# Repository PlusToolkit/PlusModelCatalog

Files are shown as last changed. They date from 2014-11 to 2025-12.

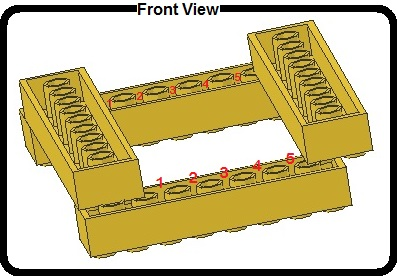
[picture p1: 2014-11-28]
fCalPhantom/fCal_L1/BuildingInstructionManual/Pictures/LegoPhantomStep2Iso.png

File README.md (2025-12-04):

# PlusModelCatalog

This repository contains 3D printable models for the Plus Toolkit

## Documentation

View the documentation at: [Read the Docs](https://plusmodelcatalog.readthedocs.io/)

## Building Documentation Locally

### Prerequisites

```bash
pip install -r docs/requirements.txt
```

This installs:
- Sphinx and extensions
- VTK for STL rendering
- Supporting packages

### Generate and Build

```bash
# Generate catalog pages from STL files
cd docs
python generate_catalog.py --repo-root .. --docs-dir .

# Build HTML documentation
sphinx-build -b html . _build/html

# View documentation
start _build/html/index.html  # Windows
# or
open _build/html/index.html   # macOS
# or
xdg-open _build/html/index.html  # Linux
```

### Quick Build Script

On Windows:
```batch
cd docs
python generate_catalog.py --repo-root .. --docs-dir .
sphinx-build -b html . _build/html
start _build\html\index.html
```

## Adding New Models

1. Add STL file to the appropriate directory (Tools, TrackingFixtures, etc.)
2. Edit the corresponding `catalog.json` file in that directory to add model metadata:
   - Add a description
   - Optionally specify explicit files if not auto-discovered
   - Optionally specify a custom preview image
3. Commit to repository
4. Documentation automatically regenerates on ReadTheDocs

### Example: Adding a New Tool

```json
// Edit Tools/catalog.json
{
  "models": {
    "MyNewTool": {
      "description": "Description of my new tool with its dimensions and purpose.",
      "files": ["MyNewTool.stl"]  // Optional if file matches model ID
    }
  }
}
```

## Contributing

Contributions of new models are welcome! Please ensure:
- STL files are clean and printable
- Include source CAD files when possible
- Add appropriate descriptions in the `catalog.json` file in the model's folder

## Support

For questions about the Plus Toolkit, visit:
- Website: https://plustoolkit.github.io/
- GitHub: https://github.com/PlusToolkit/

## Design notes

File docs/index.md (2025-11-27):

# PlusModelCatalog

Welcome to the Plus Toolkit 3D Model Catalog

```{toctree}
:maxdepth: 2
:caption: Contents:
:hidden:
catalog/tools
catalog/tracking-fixtures
catalog/fcal-phantoms
catalog/anatomy
catalog/needletutor
```

```{toctree}
:maxdepth: 1
:caption: Related Projects
:hidden:
PlusLib Documentation <https://pluslib.readthedocs.io/>
```

## About

This catalog contains freely usable, 3D-printable models of tools, tracking fixtures, calibration phantoms, and anatomical models.

## Quick Links

- [Tools](catalog/tools.md) - Tracking tools, ultrasound probes, and surgical instruments
- [Tracking Fixtures](catalog/tracking-fixtures.md) - Mounts for optical and EM trackers
- [fCal Phantoms](catalog/fcal-phantoms.md) - Calibration phantoms
- [Anatomy Models](catalog/anatomy.md) - Anatomical models for simulation
- [Needle Tutor](catalog/needletutor.md) - Components for needle insertion training

## Repository

All models are hosted on GitHub: [PlusToolkit/PlusModelCatalog](https://github.com/PlusToolkit/PlusModelCatalog)

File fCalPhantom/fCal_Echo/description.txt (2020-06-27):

fCal phantom customized for tube-shaped echo probes such as intracardiac echo (ICE) catheters and transesophageal echo (TEE) probes.
Developed by Robert Kreher (Otto-von-Guericke-University Magdeburg, Germany (https://www.ovgu.de/), Stimulate Research Campus (https://www.forschungscampus-stimulate.de/).

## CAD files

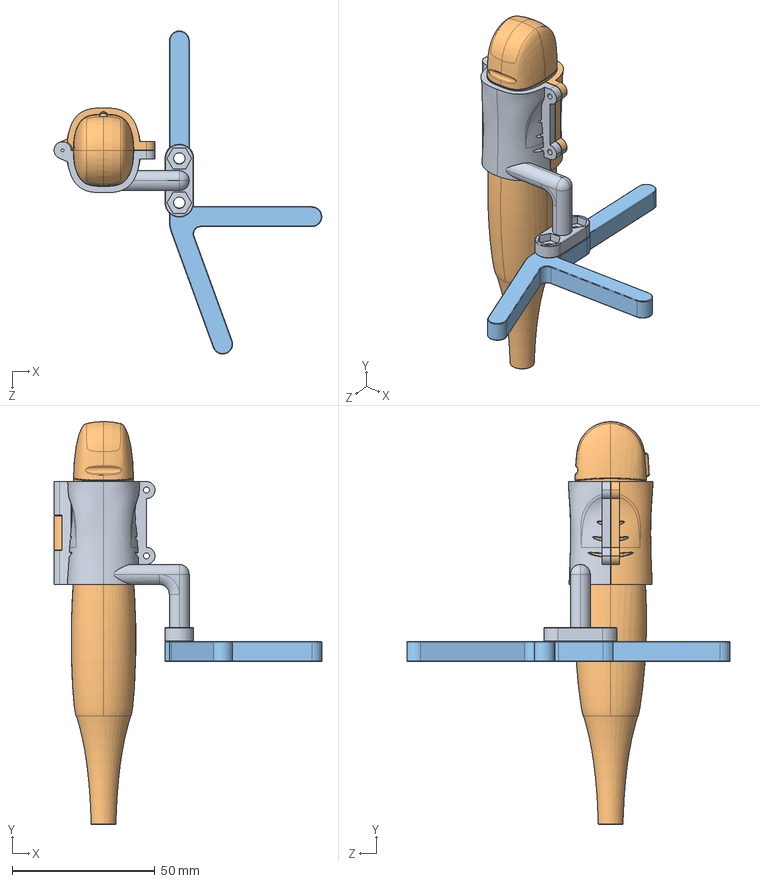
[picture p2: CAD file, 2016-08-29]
TrackingFixtures/MC10_ProbeHolder/TelemedMC10_ProbeHolder_Assembly.SLDASM
93.7 x 141.0 x 113.1 mm
TelemedMC10_ProbeHolder_MarkedSide
TelemedMC10_ProbeHolder_UnmarkedSide
TelemedMC10_ProbeHolder_OpticalTracker

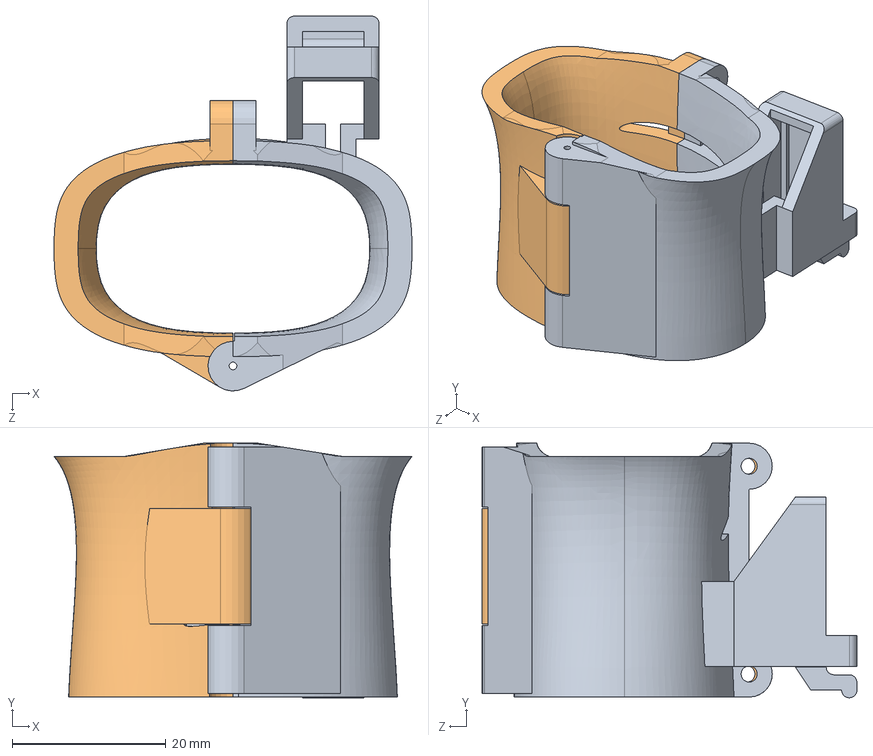
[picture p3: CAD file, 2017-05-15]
TrackingFixtures/Telemed-MicrUs-L12-SensorHolder.SLDASM
46.5 x 33.1 x 48.7 mm
TelemedHolder_L12_MarkedSide
TelemedHolder-L12_UnmarkedSide

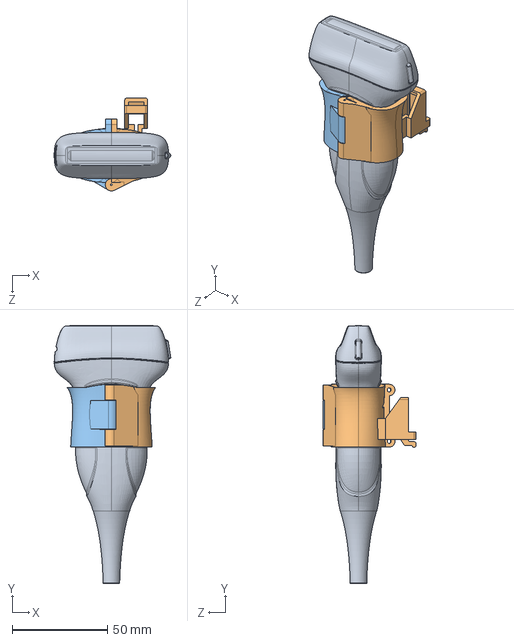
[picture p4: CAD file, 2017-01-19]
TrackingFixtures/Telemed-L12-FixtureConcept.SLDASM
61.2 x 135.3 x 48.7 mm
TelemedHolder_L12_MarkedSide
TelemedHolder-L12_UnmarkedSide

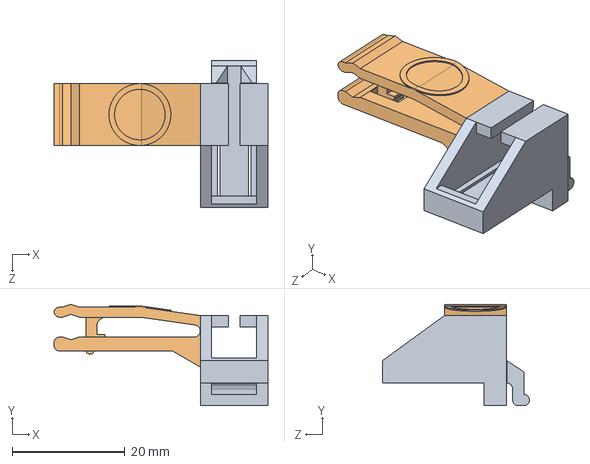
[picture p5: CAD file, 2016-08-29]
TrackingFixtures/NeedleGrabber_Parallel.SLDASM
38.0 x 18.0 x 26.1 mm
SensorHolder_2.0
NeedleGrabber_Parallel_Short

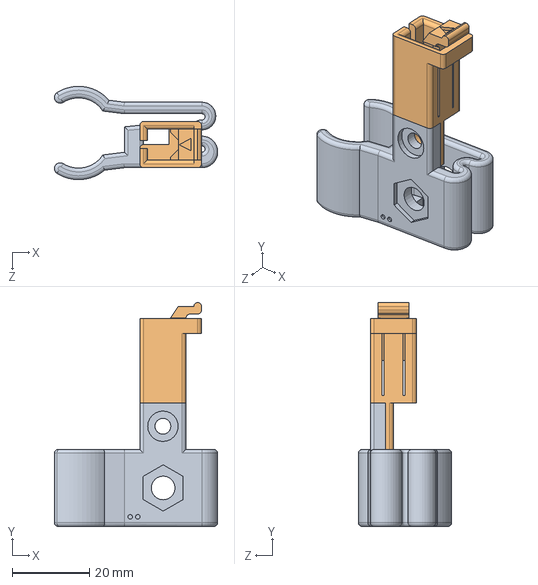
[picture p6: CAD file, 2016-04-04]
TrackingFixtures/CauteryTracking-Concept.SLDASM
42.4 x 58.1 x 24.2 mm
CauteryGrabber
SensorHolder-OneHole

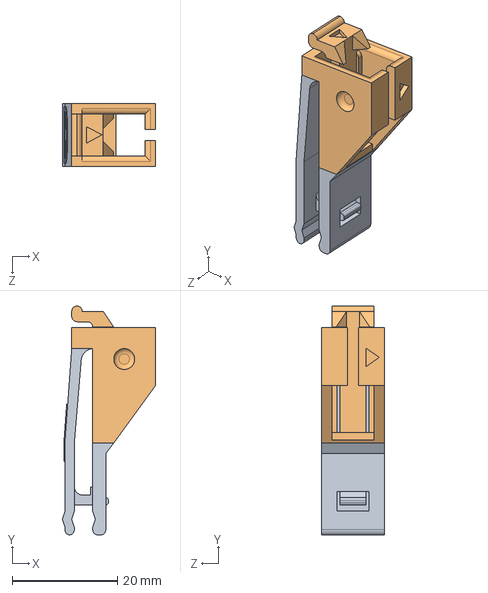
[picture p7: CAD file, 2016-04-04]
TrackingFixtures/NeedleClip-Assembly_16-20G.SLDASM
17.8 x 43.6 x 12.0 mm
NeedleGrabber_16-20G
SensorHolder_2.0

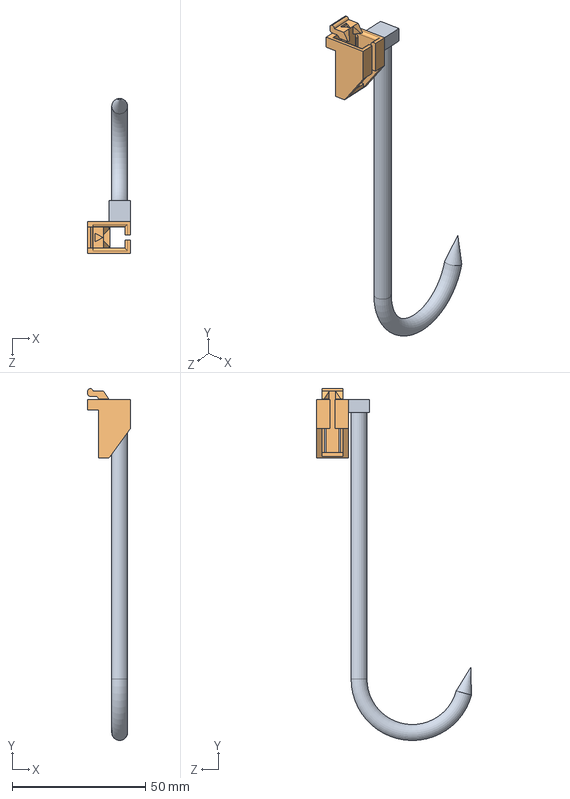
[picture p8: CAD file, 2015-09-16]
TrackingFixtures/Stylus_Candycane_100mm_WithHolder.SLDASM
16.0 x 132.1 x 58.2 mm
CandyCaneTip_100mm
SensorHolder_2.0

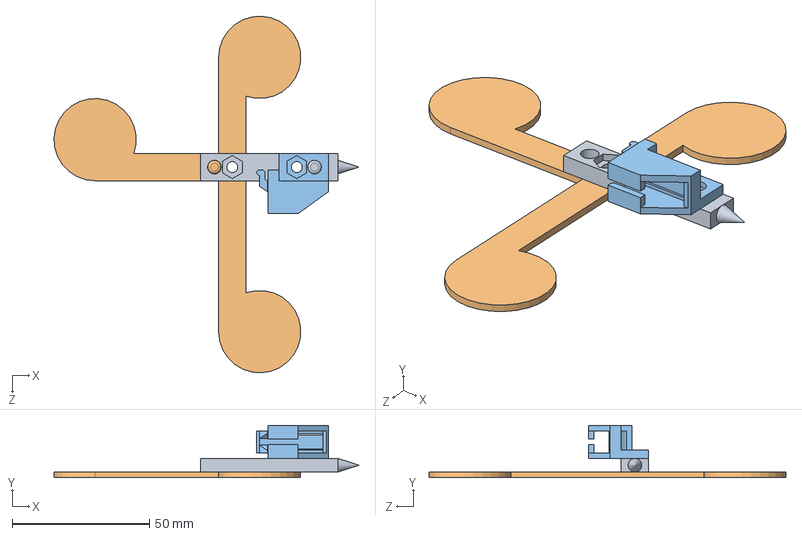
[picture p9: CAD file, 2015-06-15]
TrackingFixtures/MicronAscensionTracking-Concept.SLDASM
111.2 x 19.0 x 130.0 mm
Pointer-TwoConnectors
MicronPlate01
SensorHolderConnector_1.0

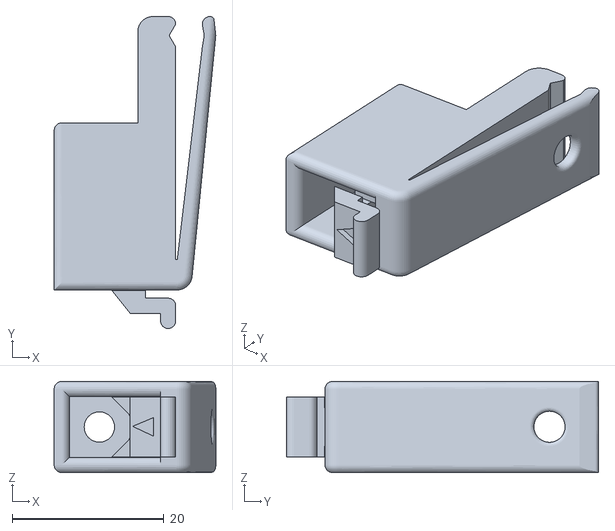
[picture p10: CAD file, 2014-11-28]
TrackingFixtures/NeedleGrabberFlappy-Assembly_1.0.stl
21.3 x 41.1 x 12.0

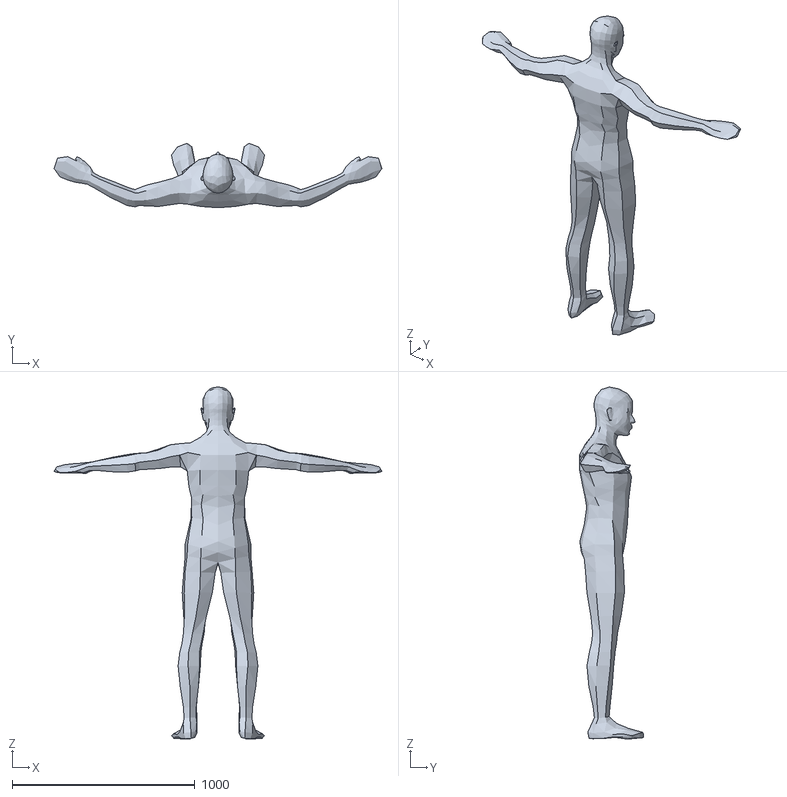
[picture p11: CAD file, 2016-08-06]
Anatomy/HumanSimple.stl
1795.8 x 352.8 x 1927.8

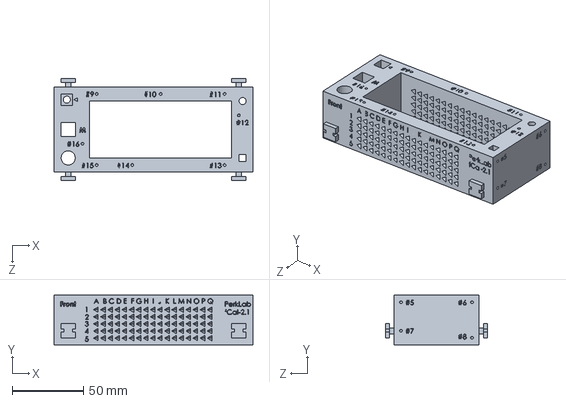
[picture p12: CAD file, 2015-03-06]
fCalPhantom/fCal_2/fCal_2.1.SLDPRT
140.0 x 35.0 x 72.0 mm

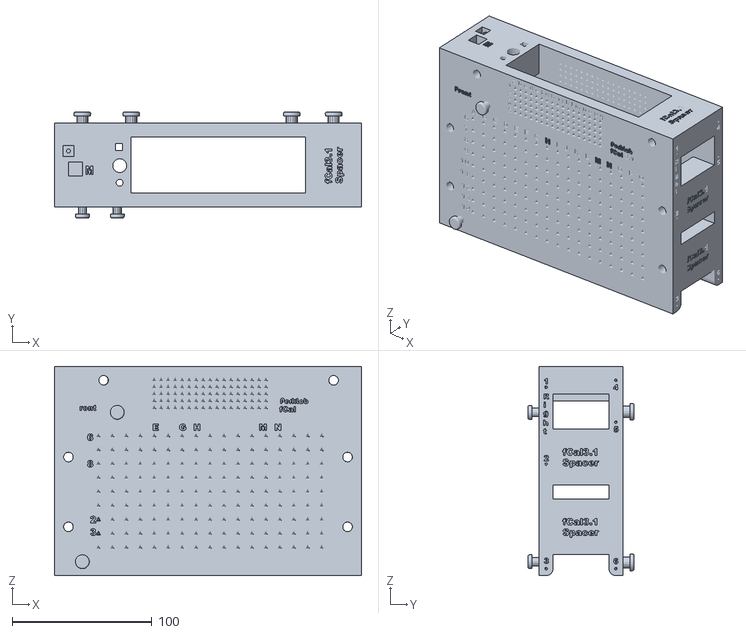
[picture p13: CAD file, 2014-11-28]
fCalPhantom/fCal_3/fCal_3.1.stl
220.0 x 76.0 x 150.0

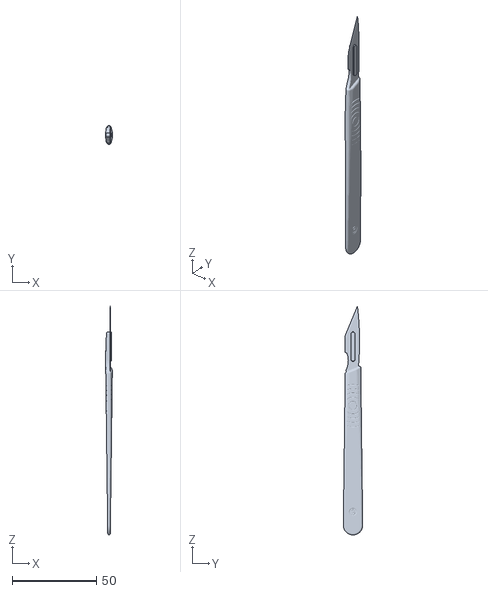
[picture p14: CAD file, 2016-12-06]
Tools/Scalpel.stl
3.97 x 11.4 x 135.7

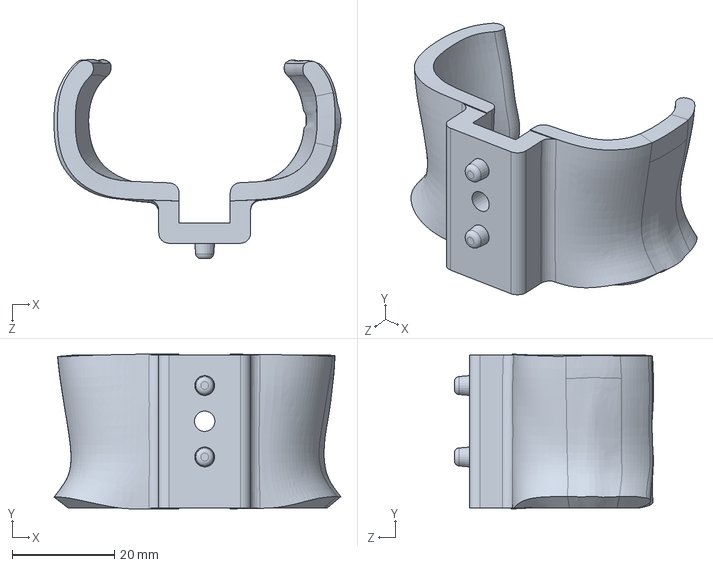
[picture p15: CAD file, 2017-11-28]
TrackingFixtures/GE_ML6-15-D/GeMl615D_Clip_v01.SLDPRT
56.2 x 30.3 x 39.0 mm

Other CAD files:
TrackingFixtures/MC10_ProbeHolder/TelemedMC10_ProbeHolder_MarkedSide.SLDPRT
TrackingFixtures/MicronTracker/MarkerHolder_120mm_Winged_1.0.stl
TrackingFixtures/MultiModalityTracking/SolidWorks/peg1.SLDPRT
TrackingFixtures/OpticalMarkerTracker/Marker-80.SLDPRT
Tools/Cautery.SLDPRT
Tools/Cautery.stl
Tools/Needle_BardDuaLok57.stl
Tools/UsProbe_SPL40.stl
Tools/UsProbe_Telemed_L12.stl
Tools/UsProbe_Ultrasonix_C5-2_60.stl
Tools/UsProbe_Ultrasonix_EC9-5_10.stl
Tools/UsProbe_Ultrasonix_L14-5_38.stl
TrackingFixtures/ArmL-30.STL
TrackingFixtures/Ascension800Holder_ThreeHolesSide.SLDPRT
TrackingFixtures/Ascension800Holder_ThreeHolesSide.STL
TrackingFixtures/Ascension800Holder_ThreeHolesUp.SLDPRT
TrackingFixtures/Ascension800Holder_ThreeHolesUp.STL
TrackingFixtures/AscensionStyleAuroraHolder_1.0.SLDPRT
TrackingFixtures/AscensionStyleAuroraHolder_1.0.STL
TrackingFixtures/Block4x4-ThreeHoles.SLDPRT
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

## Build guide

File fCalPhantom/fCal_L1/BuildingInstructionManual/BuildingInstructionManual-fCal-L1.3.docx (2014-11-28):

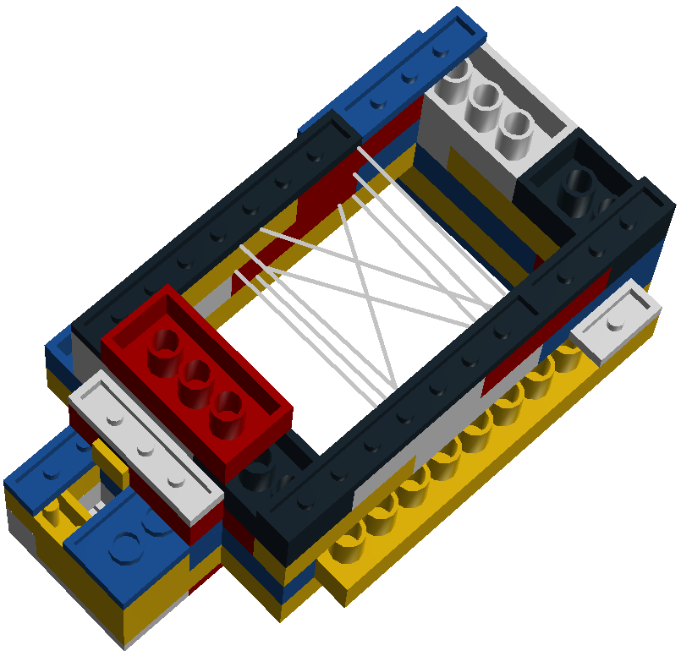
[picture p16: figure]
LegoPhantom1
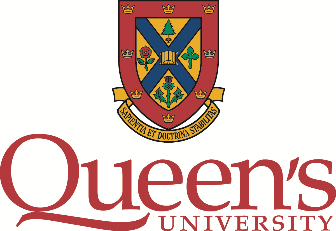
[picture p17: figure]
QueensLogo_Full_4C
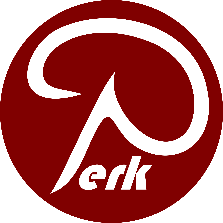
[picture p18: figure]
PerkLogo2010-round-1200dpi

Queen’s University Laboratory for Percutaneous Surgery

## Introduction

This instructional booklet is a detailed explanation of how to build the Lego Phantom. The approximate building time is 30 minutes.

## Developer

This Lego Phantom design and instructional booklet were developed in the Queen's University Laboratory for Percutaneous Surgery (http://perk.cs.queensu.ca/) (Perk Lab) in Kingston, Ontario by Ryan Walsh in June 2013.

## Purpose

The purpose of this instruction booklet is to clearly describe the process of building an identical phantom from a cheap and accessible material (ie. Lego). The Lego Phantom is to be used during the calibration of an ultrasound imager using fCal from the Plus Library (https://www.assembla.com/spaces/plus/wiki). The goal of this project was to create the phantom from a material that is readily available to any person and relatively cheap (less than $20 CAD). The Lego Phantom was also required to maintain the precision and accuracy of other phantom models (less than 1 millimetre of error). This will allow any experiments performed in the Perk Lab (http://perk.cs.queensu.ca/) be easily recreated in any other lab.

## Provided Components

1. This instructional booklet (InstructionManual.pdf)
2. A 3D CAD file of the Lego Phantom to be used in fCal (LegoPhantom.stl)
3. A configuration file of the Lego Phantom to be used in fCal (PlusConfiguration_Sonix_Ascension_LegoPhantom.xml)

## Excluded Components

1. Lego blocks (Lego blocks can be purchased in 24 different countries here (http://shop.lego.com/en-CA/Pick-A-Brick-ByTheme))
2. Wire
3. fCal, the Plus Library and other software (fCal and the Plus Library can be found here (https://www.assembla.com/spaces/plus/wiki))
4. Ultrasound Imager and other related hardware
5. Sonix GPS and Ascension Technology Corporation 3D tracking related hardware

## Preparation

It is recommended that all Lego blocks be washed before they are used in the Lego Phantom to remove any large particles that could create noise during Spatial Calibration in fCal. Washing instructions can be found here (http://service.lego.com/en-us/helptopics/) under Products->General Product Queries->How do I sanitize or wash my LEGO Elements.

## Proper Lego Phantom Orientation

To understand the proper orientation of the Lego Phantom, refer to Figure 1.

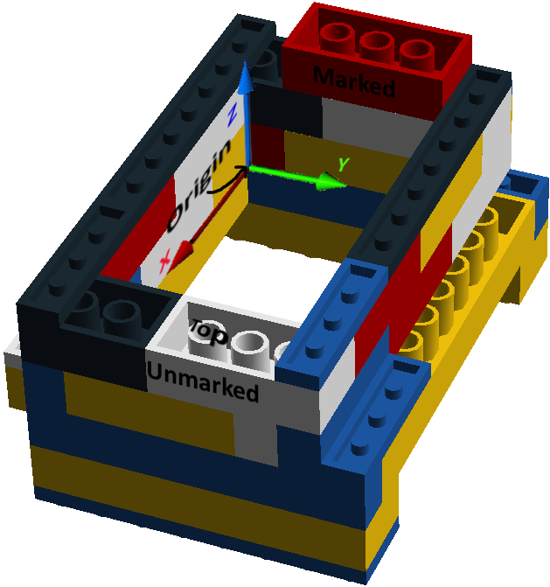
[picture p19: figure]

Figure 1: Lego Phantom Orientation and Coordinate System

Note that the phantom is designed to be used in a way that may seem “upside down” to other Lego users. Additionally, while the colour of the blocks is arbitrary and can be completely ignored, it is strongly recommended that a bright red 2x4 brick be placed on the marked side of the phantom as shown in Figure 1. This block is used to make Spatial Calibration in fCal easier for the user since an ultrasound probe has a marked and unmarked side. The marked side of the ultrasound probe should be held closest to the marked side of the Lego Phantom during Spatial Calibration. The ultrasound probe should be held above the top of the Lego Phantom while imaging the wire pattern during Spatial Calibration.

## Wire Used in the Perk Lab (http://perk.cs.queensu.ca/)

A total of 3 25 centimetre lengths of cotton yarn string were used in the Lego Phantom. Each string was used as one layer of N-Wire. The strings had a diameter of 0.3 millimetres or 0.16 millimetres when compressed. It is important that a wire has the same compressed diameter as those used in the Perk Lab (http://perk.cs.queensu.ca/) because the diameter of each wire affects their description in the Plus configuration file (PlusConfiguration_Sonix_Ascension_LegoPhantom.xml).

## N-Wire Threading

Threading instructions can be found on pages 30, 31 and 33 of this booklet. Each step corresponds to one layer of wire in an ‘N’ shaped pattern.

It is very important that the location of the wires is exactly identical on all phantoms. As a result, each wire should be pulled taught and tightly against the inside of the “nub” (the circular extrusion of the piece that will be placed above it) as shown in the diagrams. To do this, only loosely attach the Lego brick above each layer of wire. Then, when the wire is completely taught in the correct position, tightly secure the brick above the layer of wire.

## Inserting the Electromagnetic Tracker Reference

It is very important that the electromagnetic tracker reference does not move relative to the Lego Phantom during the ultrasound calibration. See Figure 2 for instructions on how to properly insert and secure the probe.

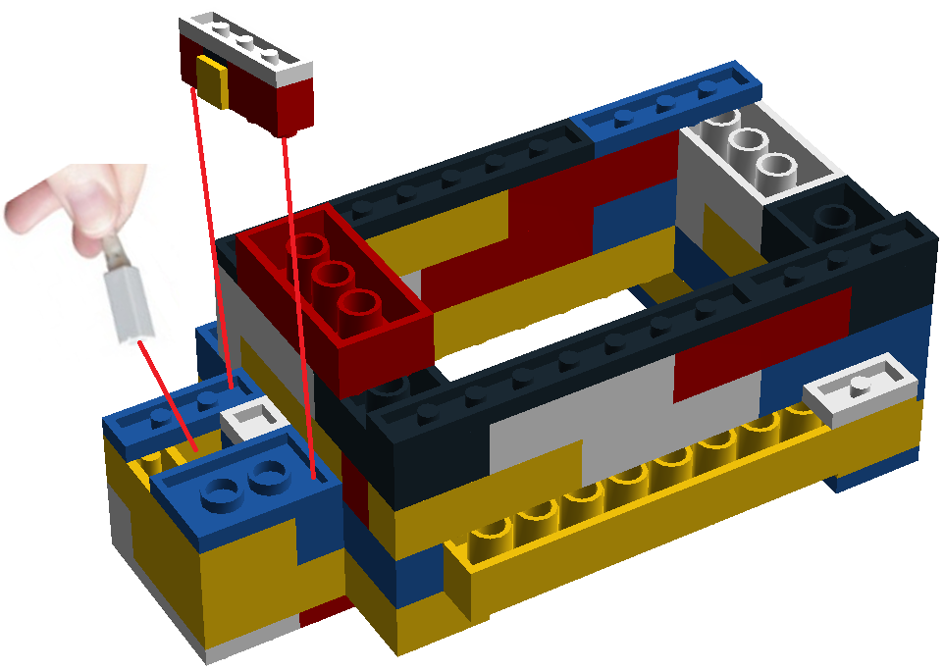
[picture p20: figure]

Figure 2: Inserting and Securing the Electromagnetic Tracker Probe

The orientation of the electromagnetic tracker reference does not matter, but it is important that it is inserted all the way into its slot and tightly secured by the clamp piece.

## Registration Landmarks

Registration landmarks are used during the Phantom Registration in fCal. There are 8 unique registration landmarks on the Lego Phantom that must be identified in order. Refer to Figure 3 for the location of each registration landmark.

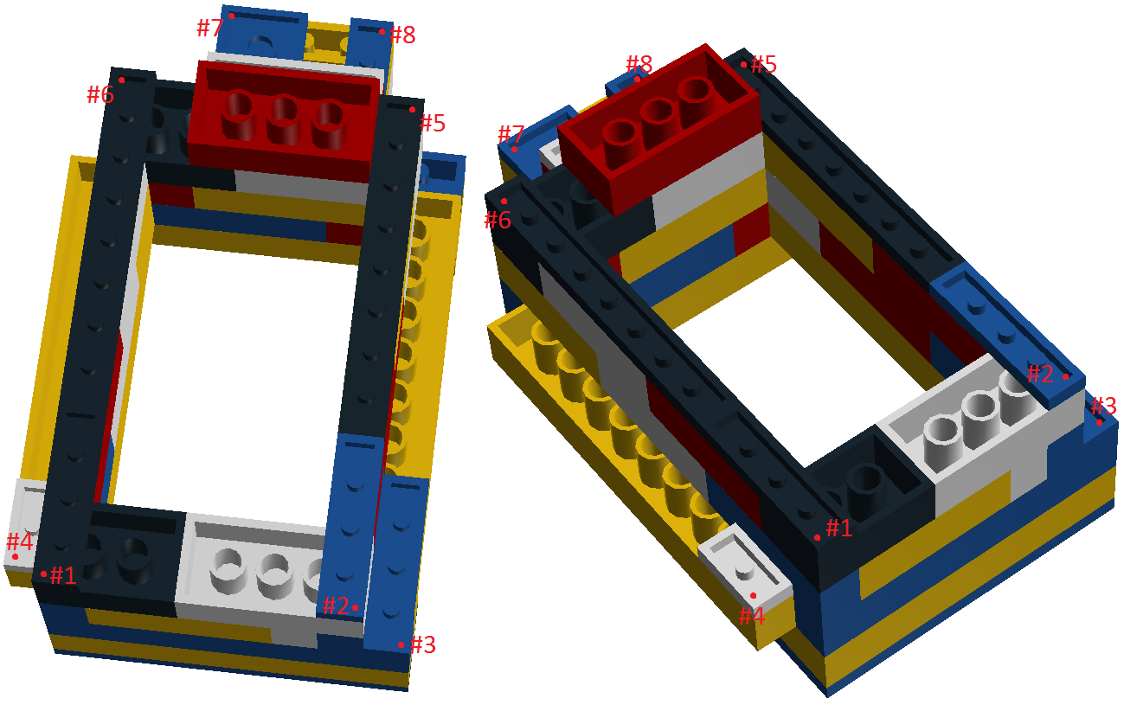
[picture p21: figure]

Figure 3: Location of the Lego Phantom registration landmarks

Note that – in order to define a unique point – when identifying these reference points, the stylus tip should be inserted into the tile piece and pressed against the bottom corner where the two edges meet.

## Important Information

The purpose of this instructional booklet is not to teach a user how to use fCal and the Plus Library (https://www.assembla.com/spaces/plus/wiki). Therefore, it is assumed that the user has a working knowledge of ultrasound calibration using fCal in the Plus Library (https://www.assembla.com/spaces/plus/wiki).

In order to be able to visualize the Lego Phantom during Phantom Registration in fCal, the Plus configuration file (PlusConfiguration_Sonix_Ascension_LegoPhantom.xml) must contain the path of the 3D CAD file (LegoPhantom.stl). Since each user may have a different path, none has been included in the provided Plus configuration file (PlusConfiguration_Sonix_Ascension_LegoPhantom.xml). Therefore, if a user wishes to change the directory of either the Plus configuration file or the 3D CAD file, they must add the absolute path (from the root directory) of the 3D CAD file to line 105 of the Plus configuration file.

Not all Lego blocks need to be identical to those used in this instruction set. The purpose of the Lego Phantom is to be accessible to anyone anywhere in the world. Therefore, things like colours of the blocks (it is strongly recommended that the bright red 2x4 brick on the marked side of the Lego Phantom be included for orientation purposes), symbols on them and even the number of blocks used (eg. a 2x4 brick can be replaced with 2 2x2 bricks as long as the dimensions of the Lego Phantom as a whole do not change) are unimportant. However, it is crucial that the location of each NWire’s start and end point and each reference point be exactly where they are shown in this instructional booklet for a proper ultrasound calibration.

The Lego Phantom model described in this instructional booklet is 1.3.

## Frequently Asked Questions

Question: I am getting a large error (greater than 1 millimetre) after I perform a Spatial Calibration in fCal. What is wrong?

Answer: There must be an inconsistency between your Lego Phantom N-Wire pattern and the one described in the provided Plus configuration file (PlusConfiguration_Sonix_Ascension_LegoPhantom.xml). You should try carefully threading your Lego Phantom another time. If you wish to view the Plus configuration file to find any discrepancies and fix them (either in the configuration file or on your Lego Phantom), open the plus configuration file with a text editor. On lines 146 through 158, you will find the ordered threetuples describing the x, y, and z coordinate of the start point and end point of each wire spanning the Lego Phantom (the x, y and z values are in millimetres from the origin). Refer to Figure 1 in the Proper Lego Phantom Orientation section to understand the phantom coordinate system.

## Parts List

## Building Instructions

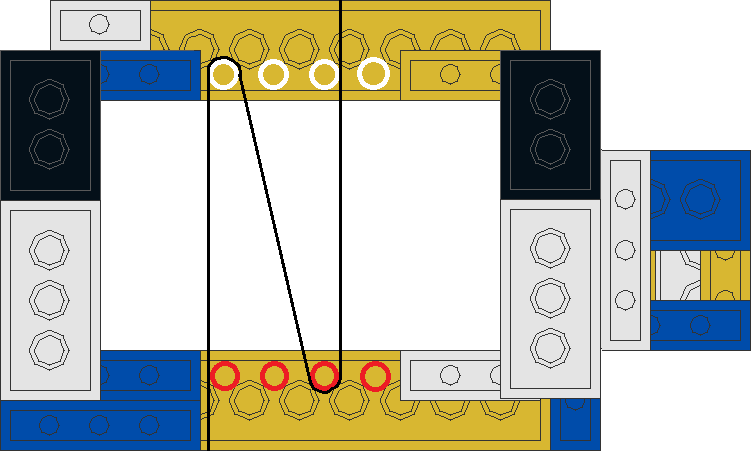
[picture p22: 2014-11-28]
fCalPhantom/fCal_L1/BuildingInstructionManual/Pictures/bottomNWire_above.png

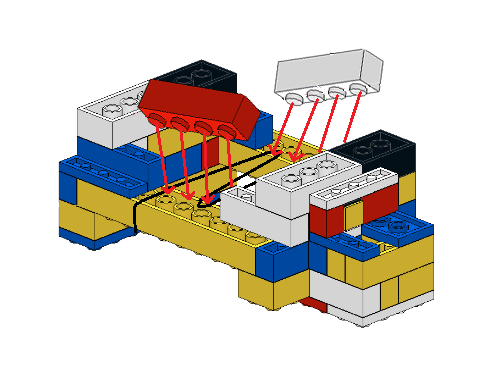
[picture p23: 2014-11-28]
fCalPhantom/fCal_L1/BuildingInstructionManual/Pictures/bottomNWire_iso.png

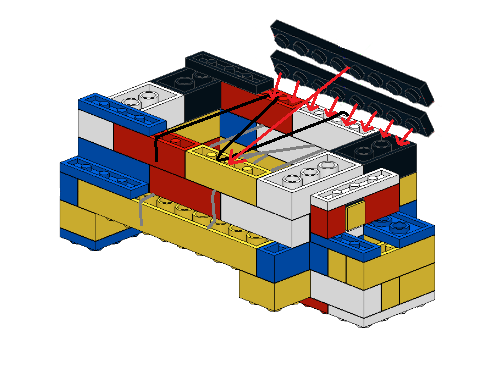
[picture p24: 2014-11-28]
fCalPhantom/fCal_L1/BuildingInstructionManual/Pictures/topNWire_iso.png

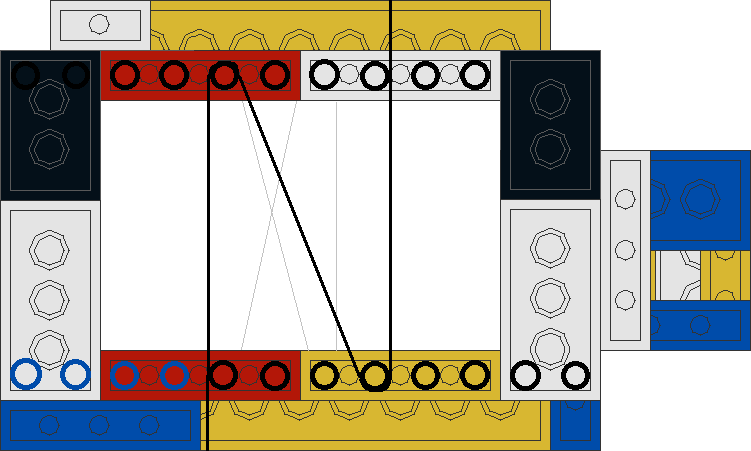
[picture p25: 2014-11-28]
fCalPhantom/fCal_L1/BuildingInstructionManual/Pictures/topNWire_above.png

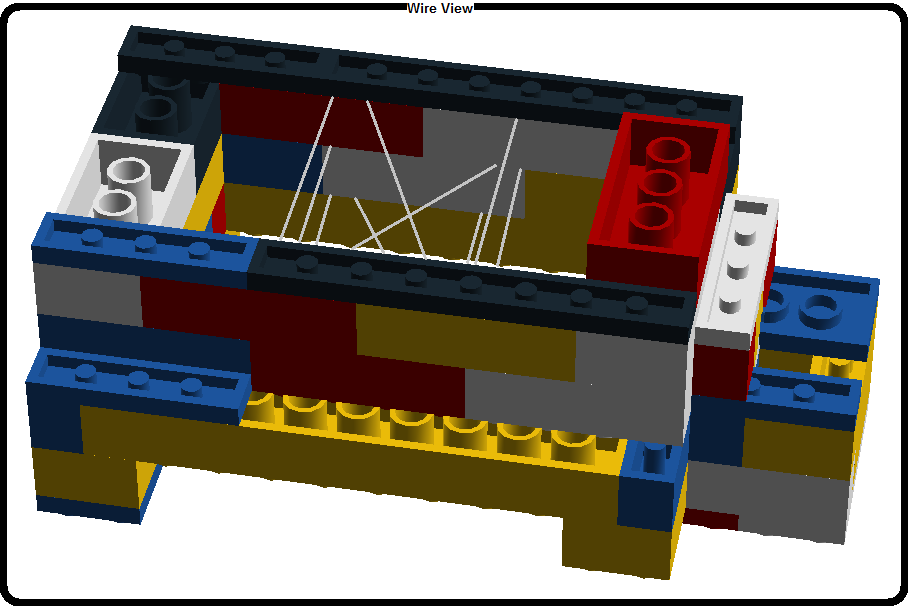
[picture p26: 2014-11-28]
fCalPhantom/fCal_L1/BuildingInstructionManual/Pictures/LegoPhantom1.3_wireView.png

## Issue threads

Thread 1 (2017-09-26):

Create clip-on fixture for Telemed ultrasound probes

Sunderlandkyl, 2017-09-26:
(No description)

Migrated from https://app.assembla.com/spaces/plus/tickets/1183/details

Sunderlandkyl, 2017-10-19:
This issue was moved to PlusToolkit/PlusLib#236

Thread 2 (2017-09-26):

Create printable markers compatible with Medronic Stealth Station

Sunderlandkyl, 2017-09-26:
(No description)

Migrated from https://app.assembla.com/spaces/plus/tickets/1189/details

Sunderlandkyl, 2017-09-26:
2017-05-09 11:01
Tamas Ungi
Re #1189: One tool added.
Committed to: plus
In plus:5073

Sunderlandkyl, 2017-10-19:
This issue was moved to PlusToolkit/PlusLib#237

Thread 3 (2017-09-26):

Move all EM field distortion mapping tool models to model catalog

Sunderlandkyl, 2017-09-26:
SlicerIgtAssembla\EmFieldDist\models

Migrated from https://app.assembla.com/spaces/plus/tickets/1023/details

Sunderlandkyl, 2017-10-19:
This issue was moved to PlusToolkit/PlusLib#238

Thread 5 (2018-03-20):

STL model of Ultrasonix BPC8-4/10 & BPL9-5/55 Transrectal probe

ai-ray, 2018-03-20:
Dear All,
for a starting project, I need the 3D model of the BPC8-4/10 & BPL9-5/55 Transrectal probe.

Since I think there are other groups using the same probe, is it possible to add this model to the repository?

Thanks in advance for your support

ungi, 2018-03-20:
Hi. I haven't used those models in the past, and none of my past Ultrasonix contacts work there anymore. If you can get a copy of those models, I would be happy to add them to the repository.

lassoan, 2018-03-20:
@ungi That's the biplane transrectal Ultrasonix probe. It has a very simple geometry, so it could be probably measured and modeled relatively easily, but it would probably still take a couple of hours.

@ai-ray Would you like to try to model it using AutoCAD Fusion 360 software? (it is free)
If it helps, we may acquire a 3D scan of it that may help in the modeling.

ungi, 2018-03-20:
True. It wouldn't take much time to make a model in Fusion 360 after surface scanning. I am working on a tutorial that is very similar to this task. In this video I'm designing a clip that matches the probe surface, but the probe itself could be modeled similarly. The video is unfinished and there is no narration yet, but here is a preview: https://1drv.ms/v/s!AhiABcbe1DBygotebJEY-OcNV2cXPg

mxochicale, 2019-11-14:
Hi @ungi , thanks for sharing the nice video. I wondering if that is a CT scan of the probe and what where the parameters you used to perform the scanning. Also, it would be nice to know if there are any precautions if one decides to scan a ultrasound probe with a CT scanner.

ungi, 2019-11-14:
Yes, CT scan. I wasn't there when they scanned it, but I don't think there are any precautions. X-ray is harmless to the ultrasound transducer. The CT technician will probably have a good guess what parameters to use.

Closed 2021-08-17.

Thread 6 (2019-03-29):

suggestions for probe holder

fcenni, 2019-03-29:
Hi,
I am working on a project for making a probe holder for this probe (from Telemed company): HL9.0/60/128Z-2 transducer. I got some ideas from your previous work here http://perk-software.cs.queensu.ca/plus/doc/nightly/modelcatalog/
I have some questions: do you recommend a single part (so a bit flexible), or 2 parts with an hinge? Which material to use for printing and for the type of hinge/s? Any suggestions/feedback is welcome!
Thanks for your help,
Francesco

ungi, 2019-03-29:
Hi, ask for the CAD model of the transducer from Telemed. I have asked twice for different transducers and they have sent me the outer shell models for free. Once you have the model, you may send it to me so I can show how I would design the clip. Or you can try yourself. The best designs for me are the ones designed as one piece that elastically snaps to the probe. We don't have the latest designs on the model catalog.

u0078867, 2019-03-29:
Hi, I am Francesco's colleague who will design the probe holder (for the snap-fit markers-holder shaft we already have an idea using a cantilever). I had the feeling the single-piece solution is better. We have a couple of 3D FDM printers here available. What material would you suggest? Nylon fibers? How thick would you recommend the elastic probe "jacket"? The thinner the more flexible, but also the more fragile ...

Thanks and regards!

ungi, 2019-03-31:
Hi, I have not experimented with different materials or settings. Some of our printers have PLA, and other ABS, both work. I use 0.8 mm shell thickness (2x nozzle diameter). And 15-20% infill. The clip itself is 3-4 mm thick, depending on how tight we want it. I usually just experiment with 0.1-0.2 mm offsets inside to make it more stable. I'm sharing this information as a reference point for you, but I'm sure these are not the optimal settings. But when a clip just works for me, I stop improving it for lack of time.

u0078867, 2019-11-14:
Forgot to closer this, but we came up with a our own design, we can share it if useful to the community.

Closed 2021-08-17.

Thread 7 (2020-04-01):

How to assemble fCal3 phantom

timirbarua, 2020-04-01:
I am building a phantom for ultrasound calibration. But confuse about which one is better between glue and screw-nuts for joining the phantom pieces. Although I prefer screw nuts but have no idea about configuration of screw-nuts for perklab fcal3.1 phantom. If anybody has any idea which one is convenient and if screw-nuts please put a link for detail information. Thanks in advance.

ungi, 2020-04-01:
For calibration, your primary goal is to collect calibration points as close to the corners of the image as possible. So, your tracked calibration phantom (either N-wires or stylus tip) needs to be as close to the corners of the image as possible. I would only use fCal phantom if you have no way to use a tracked stylus to collect calibration points. E.g. you need to clip on your tracker for every procedure, you cannot clip in the same position, and you need to maintain the tracked probe sterile. Otherwise, I would just use a tracked stylus and point at the image corners with it.

timirbarua, 2020-04-02:
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
I provided the picture of phantom pieces. Could you tell me how can I attach those pieces?

lassoan, 2021-08-17:
The phantom was designed to be assembled with screw-nuts. This model shows how to put the pieces together: https://github.com/PlusToolkit/PlusModelCatalog/blob/master/fCalPhantom/fCal_3/fCal_3.1.stl

Closed 2021-08-17.

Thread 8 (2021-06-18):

stl model of GE GE C1-6-D probe

aubest, 2021-06-18:
Hi, ，is it possible to add this model to the repository? Or where can I download the GE probe 3D model?
Thank You.

lassoan, 2021-06-18:
Unfortunately, we don't have the model of this probe.

Closed 2021-06-18.

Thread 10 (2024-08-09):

Request for Assistance with 3D Printing Issues: Telemed L12 and Ultrasonics L14-5_38 STL Files

NiltonANeto, 2024-08-09:
Dear Queen's University Members,

I hope this message finds you well.

My name is Nilton, and I am part of the University of São Paulo (USP) in Brazil. I am reaching out to request your assistance with the use of STL files for 3D printing, specifically the Telemed L12 and Ultrasonics L14-5_38 models. My goal is to conduct experiments with these transducers in water, and I would like to print them to verify the sealing before using the actual transducers.

However, I am encountering an issue during the printing process. The software indicates that the solid is "non-manifold," which prevents proper printing—only the supports are printed, while the shell does not appear. I was able to correct the mesh issues with the Telemed model using Fusion 360 (I am attaching the corrected file for your reference). Unfortunately, I have not been successful in resolving the issues with the L14-5_38 model (as shown in the attached image).

If possible, I would greatly appreciate it if you could provide the .obj file or the original model in a format other than STL so that I can attempt to fix the problem on my end. Alternatively, if it would be easier for you, I kindly request your assistance in correcting the issues with the L14-5_38 model.

Thank you very much for your attention and support.

Sincerely,
Nilton Assugeni Neto
Electrical Engineer, Federal University of Triângulo Mineiro (UFTM)
Master’s Student in Applied Physics to Medicine and Biology, University of São Paulo (USP)

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

[Telemed_L12.zip](https://github.com/user-attachments/files/16564094/Telemed_L12.zip)

ungi, 2024-08-09:
Hi Nilton, I got the L14-5 model from Telemed in SLDASM format. I could import it to Fusion 360. I didn't get permission to share the model on a public website like this so please contact me or Telemed directly for the model files. Thanks.

NiltonANeto, 2024-08-14:
Hi Ungi, thank you for your response. I sent you an email yesterday with my contact information, requesting details about the model.

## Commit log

2014-11-28 re #929: Moved all 3D models to a new subproject for automatic catalog generation
    [CauteryAssembly-Concept.cfg, CauteryHolder_1.0.stl, Concept_ScoliosisMicronTracker_2.0.cfg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]
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2014-12-01 Re #929: Removing old, unstable needle clip.
    [NeedleClip-Assembly_1.0.cfg, NeedleClip-Assembly_1.0.stl, NeedleClip-Assembly_1.1.cfg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]
2014-12-01 re #929: Removed obsolete MicronTracker tracking fixtures
    [MicronHolder1_v01.stl, MicronStylus-1.0.stl]
2015-01-06 Re #957: Leave a bit more room for the needle in bag.
    [NeedleGrabber-SensorBagHolder_1.0.cfg, NeedleGrabber-SensorBagHolder_1.0.stl, NeedleGrabber-SensorHolder_1.0.cfg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]
2015-01-06 Re #957: Added holes to make printer support material wash out faster.
    [NeedleHubClip-Assembly_1.5mm_1.0.cfg, NeedleHubClip-Assembly_1.5mm_1.0.stl, SensorHolder-Ordered-HolesInterface_2mm_1.0.stl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]
2015-01-06 re #957: Fixed model catalog build error (NeedleGrabber-SensorBagHolder_1.0.stl file was deleted but still kept in the catalog contents file). Also added dashboard submission scripts to get notificat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
2015-01-07 Re #957: Started working on needle hub grabber.
    [LocNeedle_1.0.stl]
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2015-01-14 Re #957: Deleting model that failed in practice.
    [NeedleHubClip-Assembly_1.5mm_1.0.cfg, NeedleHubClip-Assembly_1.5mm_1.0.stl]
2015-01-22 Re #957: Adding new SensorHolder designed in SolidWorks.
    [SensorHolder_1.0.SLDPRT, SensorHolder_1.0.STL]
2015-01-29 Re #957: Started working on needle hub grabber in SW.
    [NeedleHubGrabber_1.0.SLDPRT, locneedle_1.0.SLDPRT]
2015-02-02 Re #957: Removing old sensor holder that we don't use anymore.
    [SensorHolder.stl]
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2015-02-25 re #801: First version of the new fCal-2 phantom with triangle holes
    The landmark positions (and sensor holder positions) are different, so new config files are needed.
    [fCal-2.1.SLDPRT, fCal-2.1.stl]
2015-02-25 re #801: Renamed fCal_2.1 phantom files for consistency
    [fCal_2.1.SLDPRT, fCal_2.1.stl]
2015-03-06 re #801: Added second sensor fix hole and some additional labels to fCal_2.1 phantom. Added geometry description file.
    [fCal_2.1.SLDPRT, fCal_2.1.stl]
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2015-05-06 Re #990: Adding peg for Polaris reflective balls.
    [PolarisPeg.SLDPRT]
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2015-06-09 Re #990: Needle clip in SW 2015 format. Image added for printer orientation.
    [NeedleClip-Assembly_16-20G.SLDASM, NeedleClip-Assembly_16-20G.STL, NeedleGrabber_16-20G.SLDPRT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]
2015-06-12 Re #990: Clipping part was too weak. Also made the sensor bracket flexible.
    [NeedleClip-Assembly_16-20G.SLDASM, NeedleClip-Assembly_16-20G.STL, NeedleGrabber_16-20G.SLDPRT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]
2015-06-15 Re #990: Micron-Ascension dual tracker fixture.
    [MicronAscensionTracking-Concept.SLDASM, MicronPlate01.SLDPRT, NeedleClip-Assembly_16-20G.SLDASM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]
2015-06-15 Re #990: Working on Micron-Ascension dual tracking parts.
    [MicronAscensionTracking-Concept.SLDASM, MicronPlate01.STL, NeedleClip-Assembly_16-20G.STL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]
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2015-12-02 Re #990: Updated NeedleClip, and started orientation marker in SW.
    [NeedleClip-Assembly_16-20G.SLDASM, NeedleClip-Assembly_16-20G.STL, OrientationLR-Plane.SLDPRT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]
2015-12-03 Re #990: Making sensor holder more general. New OrientationLR tool for more tape space and SW format.
    [NeedleClip-Assembly_16-20G.SLDASM, OrientationLR-Plane.SLDPRT, OrientationLR-Plane.STL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]
2015-12-03 Re #990: Removing old needle clip, adding STL for new.
    [NeedleClip-Assembly_1.5mm_2.0.cfg, NeedleClip-Assembly_1.5mm_2.0.stl, NeedleClip-Assembly_16-20G.STL]
2015-12-04 Re #990: WIP making SW version of cautery tracker, and making it smaller at the same time.
    [CauteryGrabber.SLDPRT]
2015-12-05 Re #990: Cautery fixture in SW format. Need to test if this new size works.
    [CauteryAssembly-Concept.STL, CauteryGrabber.SLDPRT, CauteryGrabber.STL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]
2015-12-05 Re #990: Cautery fixture. Adding files for printing and catalog.
    [SensorHolder-OneHole.STL]
2015-12-09 Re #990: Making cautery grabber tighter. NeedleClip easier to clip.
    [CauteryAssembly-Concept.STL, CauteryAssembly-Concept.cfg, CauteryGrabber.SLDPRT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]
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2016-01-04 Re #990: Cautery grabber tighter. Cautery grabber to sensor holder interface smoother. Needle clip softer and closer to needle.
    [CauteryGrabber.SLDPRT, CauteryGrabber.STL, CauteryHolder_1.0.stl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]
2016-01-07 Re #990: Tighter cautery grabber. More solid clipping part for needle clip.
    [CauteryGrabber.SLDPRT, CauteryGrabber.STL, NeedleClip-Assembly_16-20G.SLDASM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]
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2016-01-27 Re #990: Shortened stopping bars to match angle with longer lever.
    [CauteryGrabber.SLDPRT, CauteryGrabber.STL, CauteryTracking-Concept.SLDASM]
2016-03-01 Re #990: Hinged fixture for Telemed L12.
    [Telemed-L12-FixtureConcept.SLDASM, Telemed-L12-Probe.SLDPRT, TelemedHolder-L12_UnmarkedSide.STL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]
2016-03-08 Re #990: Improving rigidity of Telemed fixture.
    [Telemed-L12-FixtureConcept.SLDASM, TelemedHolder-L12_UnmarkedSide.STL, TelemedHolder-L12_UnmarkedSide.sldprt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]
2016-04-04 Re #990: Making clues on needle clip easier to understand.
    [CauteryTracking-Concept.SLDASM, NeedleClip-Assembly_16-20G.SLDASM, NeedleClip-Assembly_16-20G.STL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]
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2016-05-11 Re #957: Adding Bard needle for virtual testing.
    [Needle_BardDuaLok57.SLDPRT]
2016-05-17 Re #990: First version of DuaLok needle hub tracker clip
    [NeedleGrabber-BardDuaLok.SLDPRT, NeedleGrabber-BardDuaLok.STL]
2016-06-28 Re #990: Adding micron tracker markers for printing with different colors.
    [Micron_Black.SLDPRT, Micron_Black.STL, Micron_Maker01-White.SLDPRT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]
2016-07-01 Re #990: Markers in v2015 and with shorter dimensions.
    [Micron_Maker01-White.SLDPRT, Micron_Maker01-White.STL, Micron_Maker02-White.SLDPRT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]
2016-08-05 re #1103: Version one of the MC10 Telemed probe holder with Polaris tracker. SLDPRT and STL files committed, ready for testing/feedback.
    [TelemedMC10_ProbeHolder_Assembly.SLDASM, TelemedMC10_ProbeHolder_MarkedSide_PARENTPART_V1.SLDPRT, TelemedMC10_ProbeHolder_MarkedSide_PARENTPART_V1.STL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]
2016-08-05 re #1103: Changed file names and added a photo of the assembly for reference.
    [TelemedMC10_ProbeHolder_Assembly.SLDASM, TelemedMC10_ProbeHolder_MarkedSide.SLDPRT, TelemedMC10_ProbeHolder_MarkedSide.STL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]
2016-08-05 re #929: Added models of US probes and a human model. Also cleaned up the catalog (mostly removed unnecessary fields).
    [CauteryGrabber.stl, CauteryModel.stl, HumanSimple.stl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]
2016-08-06 re #929: Fixed link to STL from image
2016-08-06 re #929: Fixed SimpleHuman model orientation
    [HumanSimple.stl]
2016-08-08 re #929: Added Telemed L12 probe model and Bard needle model
    [Needle_BardDuaLok57.stl, UsProbe_Telemed_L12.stl]
2016-08-09 re #1104: Basic design for the needle clip. Might make the clip shorter so the sensor is closer to the needle.
    [NeedleGrabber_Parallel.SLDASM, NeedleGrabber_Parallel.SLDPRT]
2016-08-17 re #1104: Shortened the clip so that the sensor is closer to the needle. Not sure if it is the ideal length yet.
    [NeedleGrabber_Parallel.SLDASM, NeedleGrabber_Parallel.SLDPRT, NeedleGrabber_Parallel_Short.SLDPRT]
2016-08-19 re #1103: Fixed missing parts error in the assembly.
    [TelemedMC10_ProbeHolder_Assembly.SLDASM]
2016-08-23 re #1103: Fixed missing part (Parent part) error in the assembly.
    [TelemedMC10_ProbeHolder_Assembly.SLDASM]
2016-08-29 re #1103: Located missing part(PARENTPART) within the MarkedSide part instead of in the whole assembly--not getting the part location error anymore for the MarkedSide part or the assembly.
    [NeedleGrabber_Parallel.SLDASM, TelemedMC10_ProbeHolder_Assembly.SLDASM, TelemedMC10_ProbeHolder_MarkedSide.SLDPRT]
2016-11-10 Test #1104: Added lure lock with sensor holder. Probably can only be printed with high-end printers.
    [LureLockMale.SLDPRT, LureLockMale_SensorHolder.SLDPRT, LureLockMale_SensorHolder.STL]
2016-11-10 Re #1120: Made the walls and the hinge thicker.
    [Telemed-L12-FixtureConcept.SLDASM, TelemedHolder-L12_UnmarkedSide.sldprt, TelemedHolder-L12_UnmarkedSide.stl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]
2016-11-18 Re #1104: Added holes to wash out support material. Rounded some edges.
    [LureLockMale_SensorHolder.SLDPRT, LureLockMale_SensorHolder.STL]
2016-12-05 re: #1127 V1.0 of the Ascension style holder for Aurora EM tracking fixtures.
    [AscensionStyleAuroraHolder_1.0.SLDPRT, AscensionStyleAuroraHolder_1.0.STL]
2016-12-06 re #929: Fixed origin of stylus and catuery models. Added generic cautery model.
    [Cautery.SLDPRT, Cautery.stl, CauteryModel.stl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]
2017-01-05 Re #990: Adding an optical-EM tracked tool and related files
    [PolarisAscensionPlane.SLDPRT, PolarisAscensionPlane.STL, SensorHolder_1.0.SLDPRT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]
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2017-02-26 Re #990: Adding Polaris tracking fixture for old Telemed C5 probe.
    [ArmL-30.SLDPRT, ArmL-30.STL, PolarisMarker1.SLDPRT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]
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2017-04-27 Re #1183: Made brace thicker and tighter
    [Telemed-C5-Brace.SLDPRT, Telemed-C5-Brace.STL]
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2017-05-24 Re #1183: Made it a bit tighter, and sensor at a better position
    [Ascension800Holder_ThreeHolesSide.SLDPRT, Ascension800Holder_ThreeHolesSide.STL, Medtronic_PN9733157_Marker.SLDPRT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]
2017-06-01 re #1205: Added solidworks, STL and printing images for hooked candy cane needle and marker base for Polaris tracked US calibration.
    [CandyCaneNeedleBase.SLDPRT, CandyCaneNeedleBase.STL, CandyCaneNeedleMarker.SLDPRT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]
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2017-10-23 Added a block with three holes interface for intersection with anatomical parts.
    [Block4x4-ThreeHoles.SLDPRT, Block4x4-ThreeHoles.STL]
2017-10-25 Added holes for fixing the template to the anatomy model
    [Block4x4-ThreeHoles.SLDPRT, Block4x4-ThreeHoles.STL]
2017-11-17 Fixed build failure caused by .png instead of .stl for IMAGE_PRINTABLE_FILE
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2017-11-24 Added missing piece for ultrasound optical marker fixture. Added parts to be ordered in the description of Polaris markers.
    [ArmL-30.SLDPRT, ArmL-30.STL]
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2025-11-26 Fix missing UsNeedleTutor STLs
    File extension is case sensitive on Linux.
